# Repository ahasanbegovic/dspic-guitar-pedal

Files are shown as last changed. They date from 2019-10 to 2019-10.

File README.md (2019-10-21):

# dspic-guitar-pedal
A dsPIC-based guitar pedal. It is built around a 16-bit DSP microprocessor. The project is designed to showcase some common practices in digital signal processing, PCB design and embedded programming. The A/D and D/A conversions are done using 12-bits, so the lowpass filters are designed to take away a lot of the higher frequencies, which results in a quite unique and dark sound of the pedal when it is on.

## Circuit

The circuit is designed using `Altium Designer v17.1.5 Build 472`. It is based around a [breakout board](https://download.mikroe.com/documents/full-featured-boards/easy/dspicpro-v4/dspicpro4-mcu-cards-manual-v100.pdf) designed and sold by Mikroelektronika for the [dsPIC60F6014A-PF microcontroller](http://ww1.microchip.com/downloads/en/devicedoc/70143e.pdf). The circuit supports reprogramming of the microcontroller using the [Mikroelektronika dsPIC Flash Programmer](http://www.rlx.sk/mikroelektronika/dspicflash_manual_v102.pdf). The dsPIC has an in-built 12-bit A/D converter, so the only external module (apart from the LM324 OP-AMP) is an [MCP4921 12-bit D/A converter](http://ww1.microchip.com/downloads/en/devicedoc/21897b.pdf). Third party models sourced from [SnapEDA](https://www.snapeda.com/home/). All the project files (including the third party models) can be found in the `circuit` directory. The schematic of the circuit is given below.

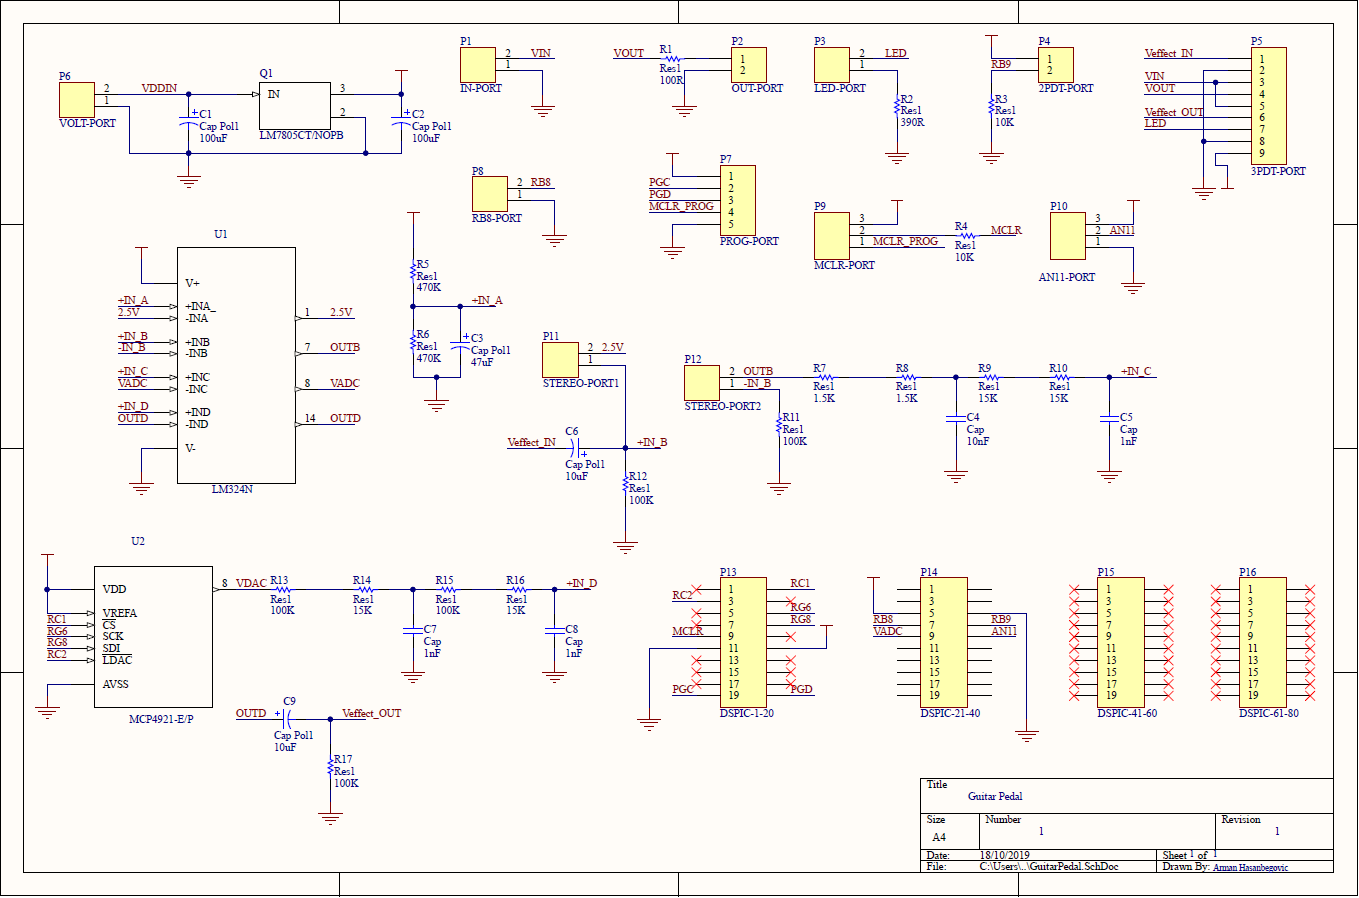
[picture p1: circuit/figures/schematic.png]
Schematic


The PCB is designed on a two-layer Eurocard. Industry-standard output files detailing the design of the PCB can be found in `circuit/Project Outputs for GuitarPedal`.

## Code

The code is written using Mikroelektronika `mikroC PRO for dsPIC v7.1.0`. The essential code (`template.c`) is written in C and given in the `code` directory, and shows how to initiate all the modules of the microcontroller needed, and how to interface the D/A Converter. An example of using that code to create a delay effect is given in `delay.c`.

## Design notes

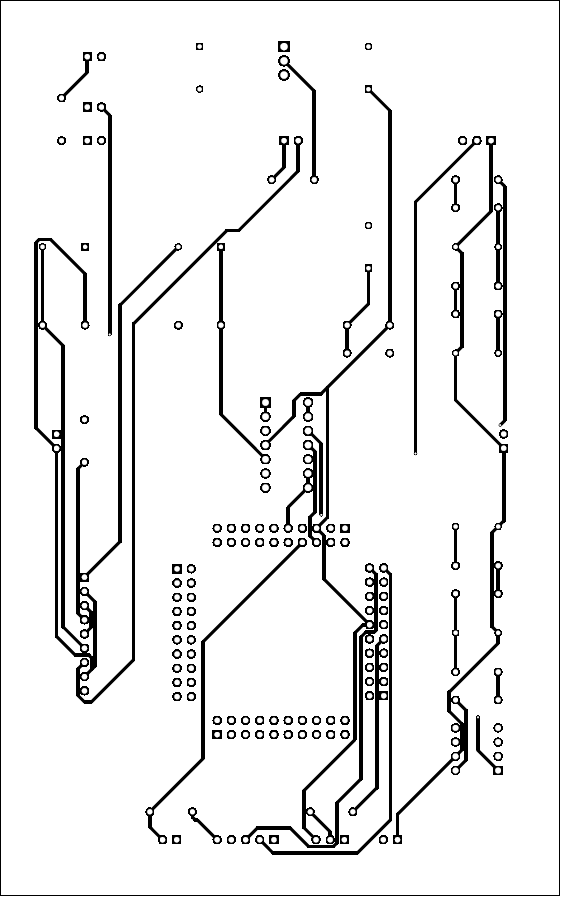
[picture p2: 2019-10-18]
circuit/figures/top_layer.png

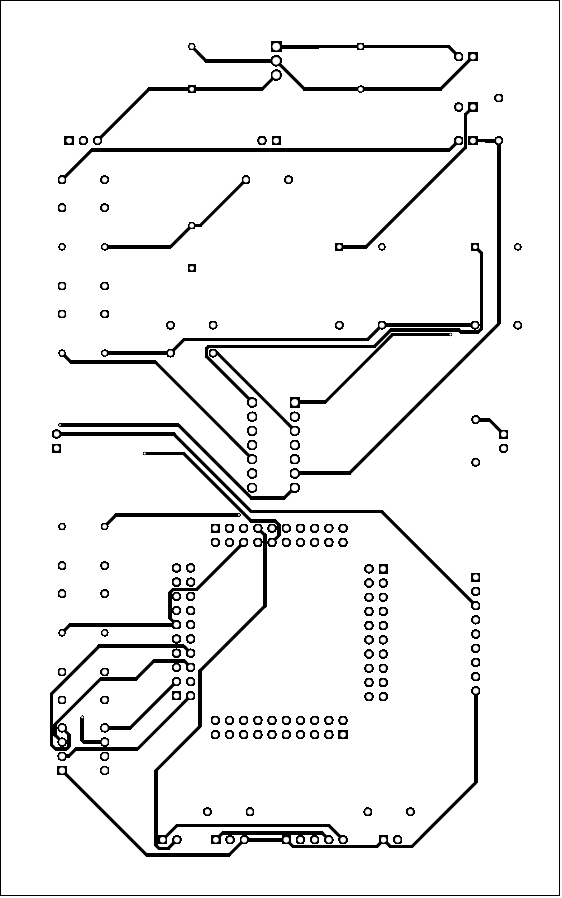
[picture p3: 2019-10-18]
circuit/figures/bottom_layer.png

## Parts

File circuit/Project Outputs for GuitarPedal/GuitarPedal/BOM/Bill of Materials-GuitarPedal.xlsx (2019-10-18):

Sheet: BOM Report
Bill of Materials |  |  | Guitar Pedal
Source Data From: |  | GuitarPedal.PrjPcb
Project: |  | GuitarPedal.PrjPcb
Variant: |  | None
Creation Date: | 18/10/2019 | 13:23:14
Print Date: | 2019-10-18 | 13:26:22
Footprint | Comment | LibRef | Designator | Description | Quantity
RAD-0.3 | Cap | Cap | C4, C5, C7, C8 | Capacitor | 4
RB7.6-15 | Cap Pol1 | Cap Pol1 | C1, C2, C3, C6, C9 | Polarized Capacitor (Radial) | 5
HDR1X2 | IN-PORT, OUT-PORT, LED-PORT, 2PDT-PORT, VOLT-PORT, RB8-PORT, STEREO-PORT1, STEREO-PORT2 | Header 2 | P1, P2, P3, P4, P6, P8, P11, P12 | Header, 2-Pin | 8
HDR1X3 | MCLR-PORT, AN11-PORT | Header 3 | P9, P10 | Header, 3-Pin | 2
HDR1X5 | PROG-PORT | Header 5 | P7 | Header, 5-Pin | 1
HDR1X9 | 3PDT-PORT | Header 9 | P5 | Header, 9-Pin | 1
HDR2X10 | DSPIC-1-20, DSPIC-21-40, DSPIC-41-60, DSPIC-61-80 | Header 10X2 | P13, P14, P15, P16 | Header, 10-Pin, Dual row | 4
*DIP254P762X508-14 | LM324N | LM324N | U1 | Ic Opamp Gp 1.2mhz 14dip | 1
*TO254P1054X470X2600-3 | LM7805CT/NOPB | LM7805CT/NOPB | Q1 | IC REG LINEAR 5V 1A TO220AB | 1
*DIP254P762X432-8 | MCP4921-E/P | MCP4921-E/P | U2 | MCP4921 Series 1 Ch 12-Bit Voltage Output Digital-to-Analog Converter-PDIP-8 | 1
AXIAL-0.3 | Res1 | Res1 | R1, R2, R3, R4, R5, R6, R7, R8, R9, R10, R11, R12, R13, R14, R15, R16, R17 | Resistor | 17
 |  |  |  |  | 45
Approved |  | Notes

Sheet: Project Information
Project Full Path | C:\Users\arman\Documents\ETF\PMBS\Altium\GuitarPedal\GuitarPedal.PrjPcb
Project Filename | GuitarPedal.PrjPcb
Variant Name | None
Data-Source Filename | GuitarPedal.PrjPcb
Data-Source Full Path | C:\Users\arman\Documents\ETF\PMBS\Altium\GuitarPedal\GuitarPedal.PrjPcb
Title | Guitar Pedal
Total Quantity | 45
Report Time | 13:23:14
Report Date | 18/10/2019
Report Date & Tine | 18/10/2019 13:23:14
Output Name | Bill of Materials
Output Type | BOM_PartType
Output Generator Name | BOM
Output Generator Description | Bill of Materials

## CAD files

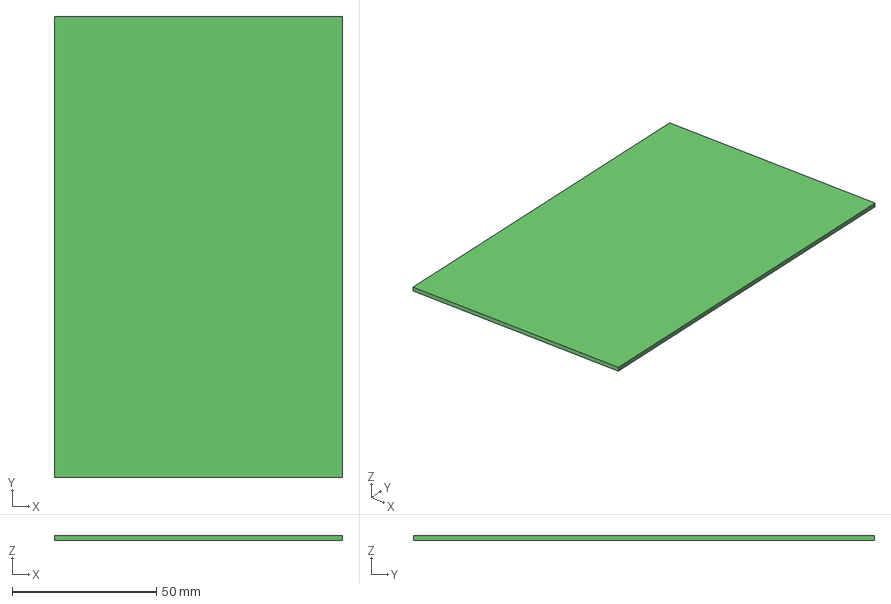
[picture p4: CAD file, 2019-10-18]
circuit/Project Outputs for GuitarPedal/GuitarPedal/ExportSTEP/GuitarPedal.step
100.0 x 160.0 x 1.69 mm

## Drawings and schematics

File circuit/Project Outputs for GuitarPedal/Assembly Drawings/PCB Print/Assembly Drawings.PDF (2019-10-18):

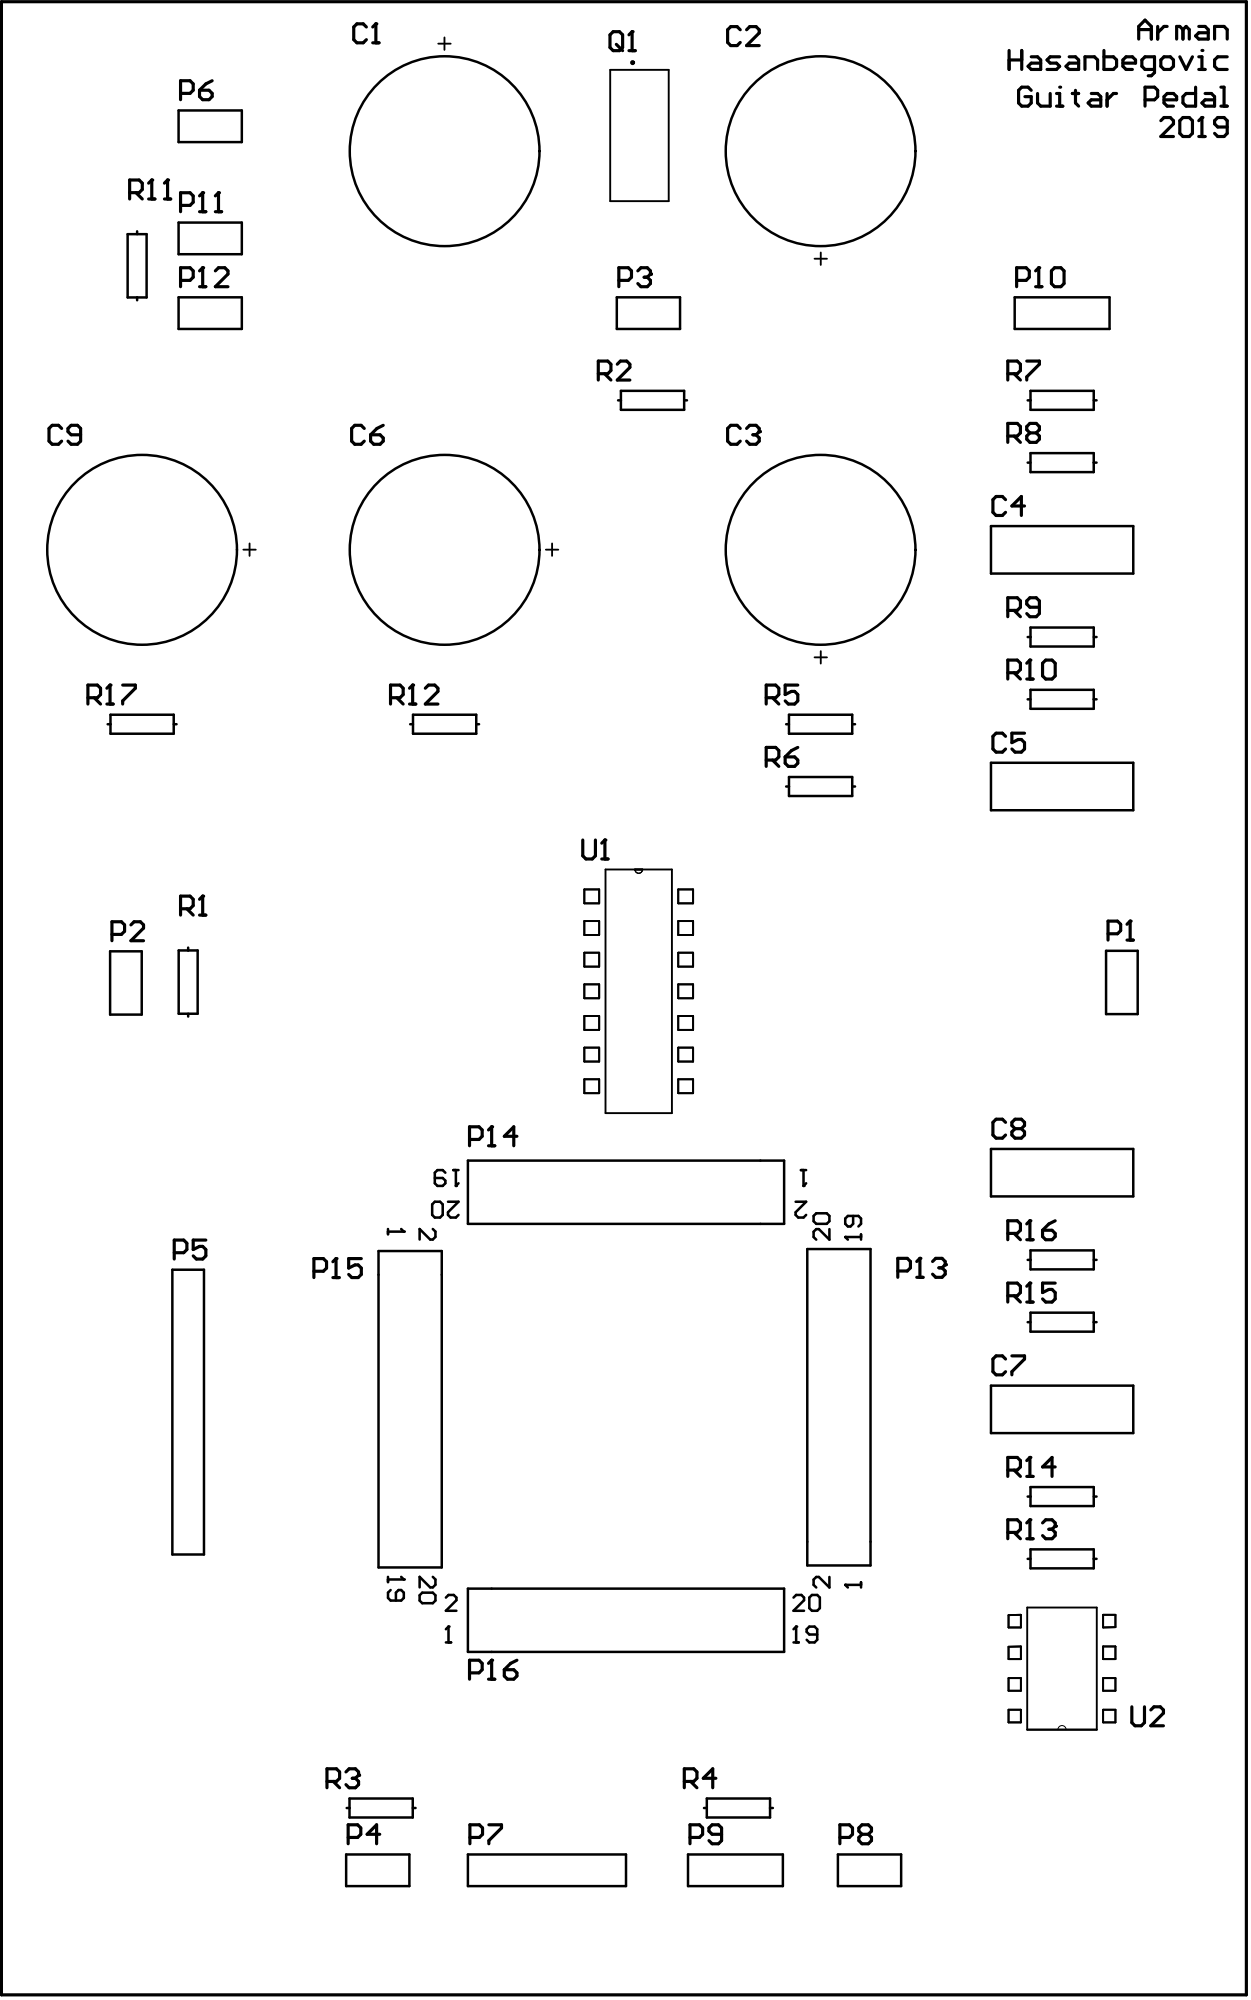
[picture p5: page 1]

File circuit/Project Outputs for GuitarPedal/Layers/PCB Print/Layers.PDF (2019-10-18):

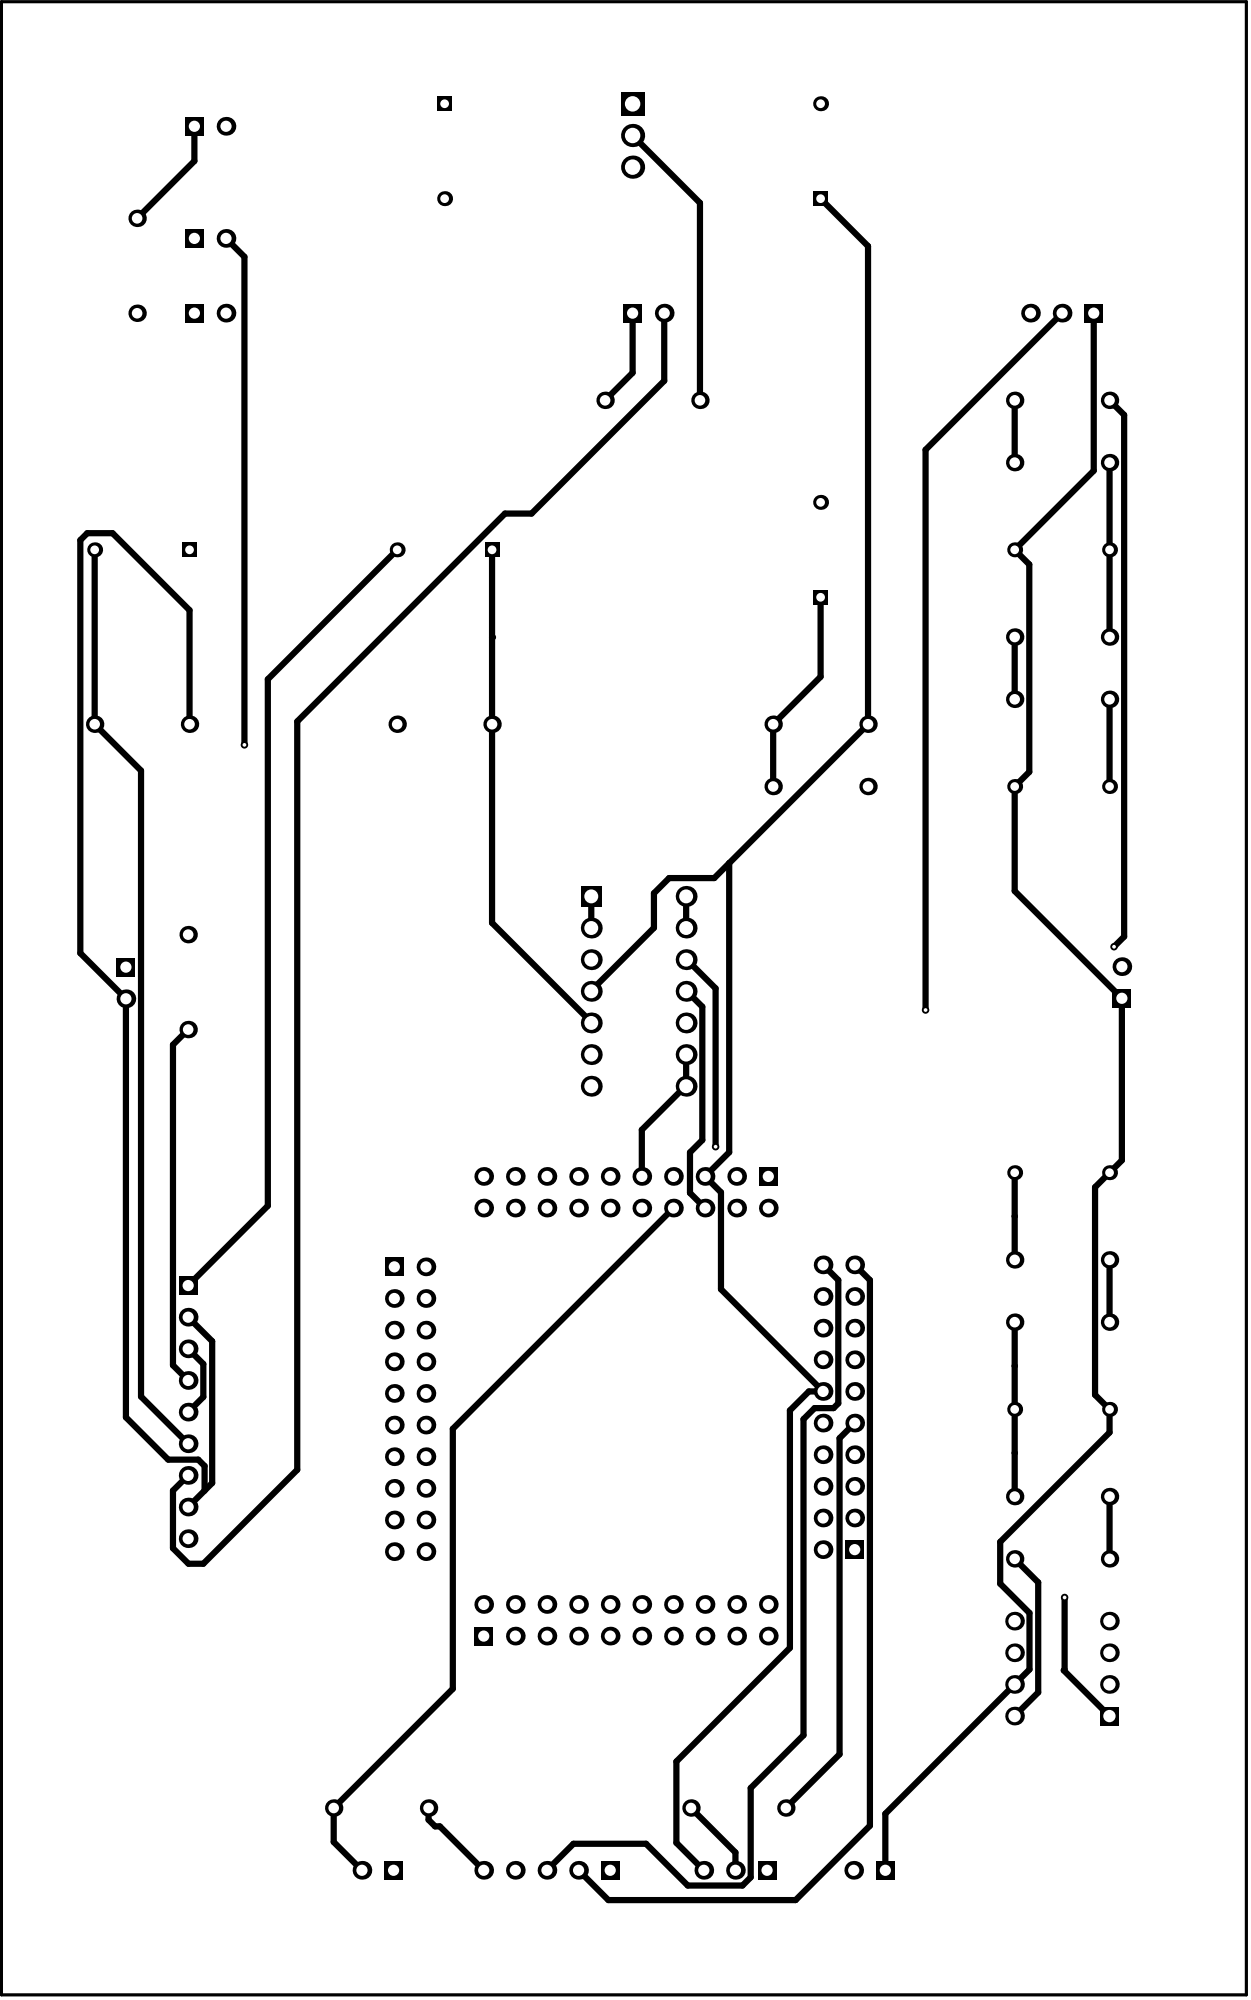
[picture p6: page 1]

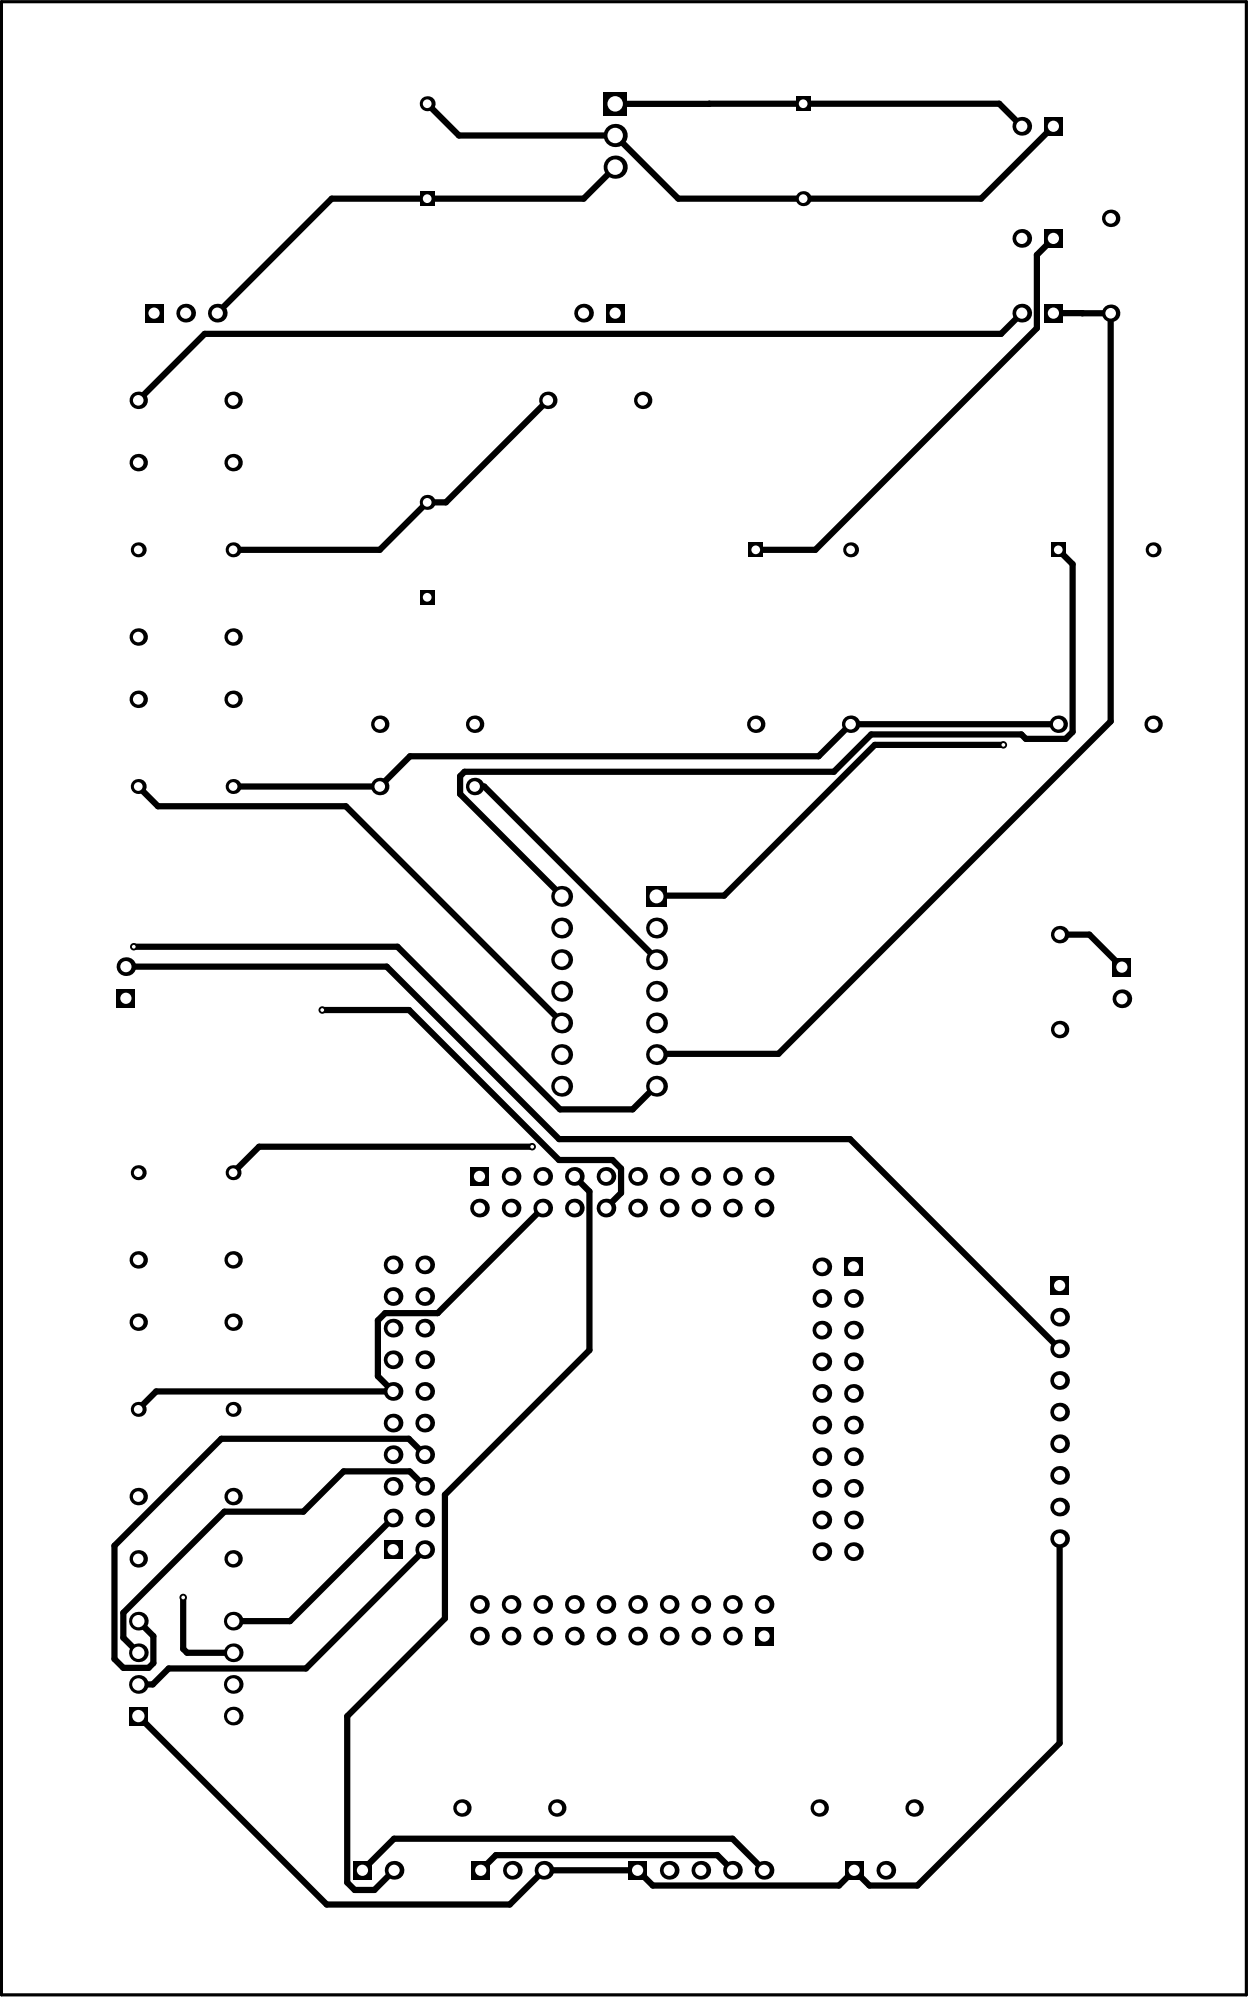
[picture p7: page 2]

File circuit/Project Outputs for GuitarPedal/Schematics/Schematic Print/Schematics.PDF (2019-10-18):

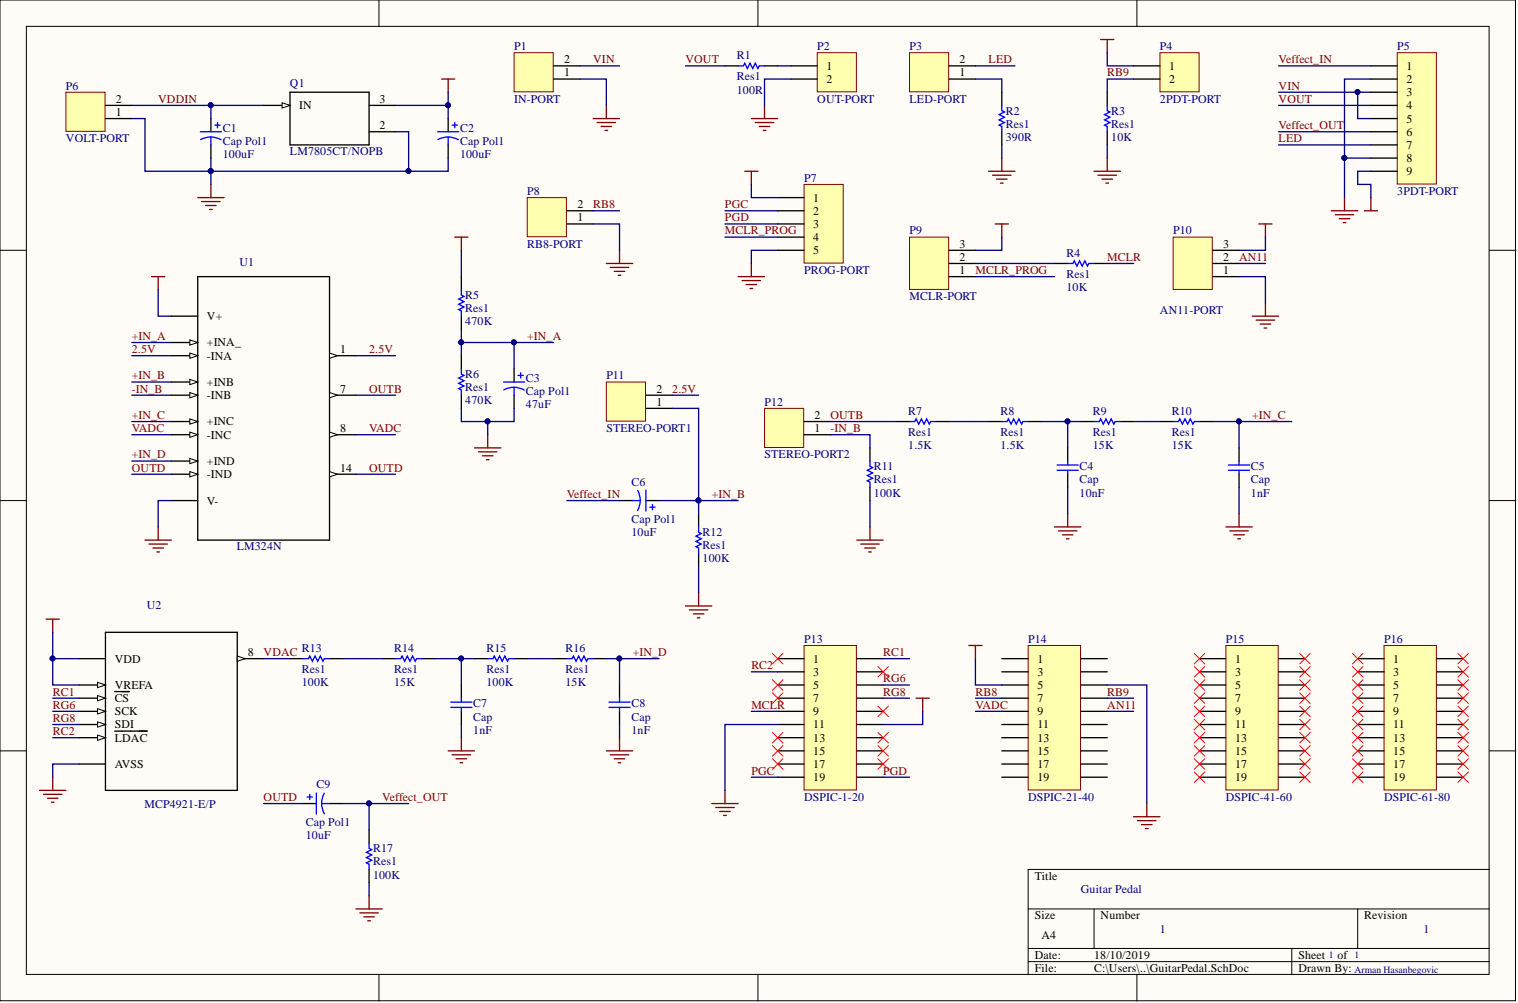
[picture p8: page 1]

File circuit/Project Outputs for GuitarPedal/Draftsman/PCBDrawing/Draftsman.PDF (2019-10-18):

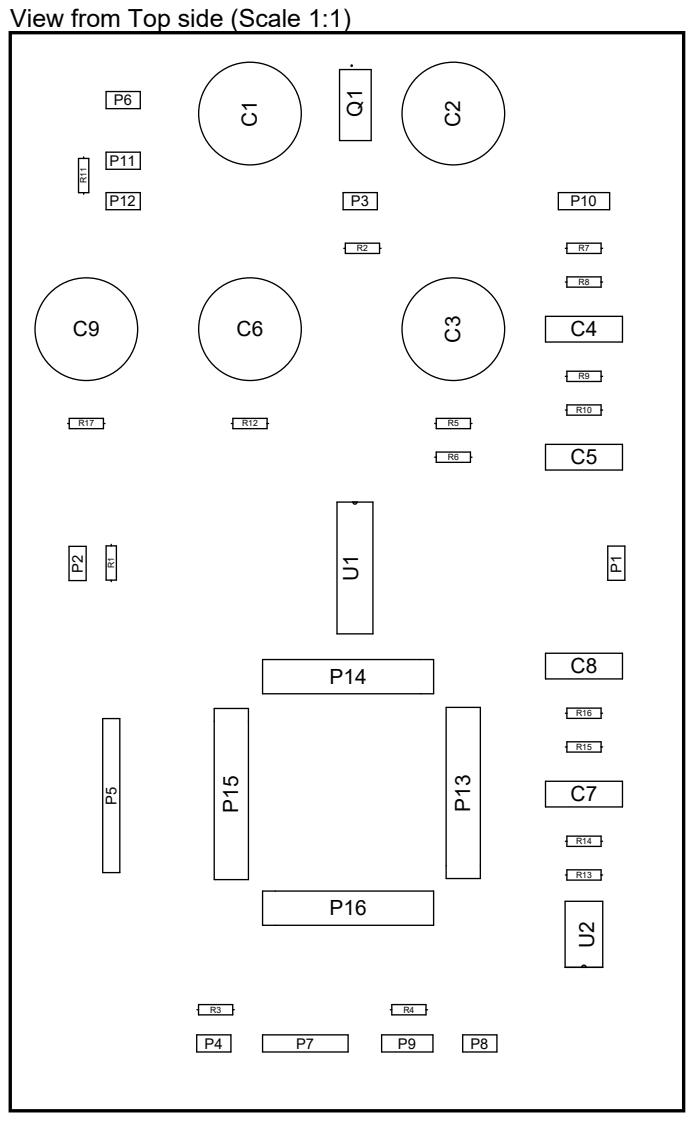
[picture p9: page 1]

View from Top side (Scale 1:1)

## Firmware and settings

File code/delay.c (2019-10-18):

const char CS_PIN = 1;
const char LD_PIN = 2;
const char AN10_PIN = 10;
const char RBx_PIN = 8;
const char IF_PIN = 0;

#define max_buffer_size 4000

unsigned int delay_buffer[max_buffer_size];
unsigned int buffer_size = max_buffer_size;
unsigned int iterator = 0;

void ADC_Init_manual(){
     ADPCFG = 0;
     ADCON1 = 0x0004;
     ADCHS = 0x000A;
     ADCSSL = 0; //No scan
     ADCON3 = 0x0F00; //TAD = internalTCY
     ADCON3 = 0x1003; //ADCS=5 (min TAD for 10MHz is 3*TCY=300ns)
     ADCON2 = 0;
     ADCON1.F15 = 1;
     ADCON1.F9 = 1;
     ADCON1.F8 = 0; // Unsigned fractional
}

int ADC_Read_manual(unsigned int channel){
     ADCHS = channel;
     ADCON1.F1 = 0; //Clear SAMP bit (trigger conversion)
     while(ADCON1.F1 == 0) {
         asm nop; //Wait for DONE bit in ADCON1
     }
     return ADCBUF0;
}

void InitMain() {
    int i;
    for(i = 0; i < max_buffer_size; i++){
       delay_buffer[i] = 2048;
    }
    ADPCFG = 0xFBFF; //10th channel is sampled and coverted
    TRISB.AN10_PIN = 1;  // Set AN0 as input
    TRISB.RBx_PIN = 0;  // Set RBx as output
    LATB.RBx_PIN = 0;
    //ADC1_Init();
    ADC_Init_Manual();

    // Spi2_Init(); // Initialize SPI2 module
    SPI2_Init_Advanced(_SPI_MASTER, // SPI in Master mode
                         _SPI_8_BIT, // 8-bit data
                         _SPI_PRESCALE_SEC_1, _SPI_PRESCALE_PRI_1, //prescaler = 1
                         _SPI_SS_DISABLE,
                         _SPI_DATA_SAMPLE_MIDDLE,
                         _SPI_CLK_IDLE_LOW,
                         _SPI_ACTIVE_2_IDLE //Falling edge
                        );

    TRISC.CS_PIN = 0; // Set CS pin as output
    TRISC.LD_PIN = 0; // Set LD pin as output


    T1IE_bit = 1;         //timer1
    IPC0 = IPC0 | 0x1000; //highest priority
    T1IF_bit = 0;         //first interrupt
    T1CON = 0x8000;       // Internal clock (20 Mhz), prescaler 1:1
    PR1= 226; // Period of Timer1 226 (interrupt every 22.6us, 44.1kHz sampling)
}//~


void DAC_Output(unsigned int valueDAC) {
    unsigned char temp;

    LATC.CS_PIN = 0; // Select DAC module
    LATC.LD_PIN = 0; // Enable data transfer



    // Send 2 bytes of valueDAC variable
    temp = (valueDAC >> 8) & 0x0F; // Prepare hi-byte for transfer
    // It's a 12-bit number, so only
    // lower nibble of high byte is used
    temp |= 0x30; // Set MCP4921 control bits
    Spi2_Write(temp); // Send data via SPI



    temp = valueDAC; // Prepare lo-byte for transfer
    Spi2_Write(temp); // Send data via SPI

    LATC.LD_PIN = 1; // Disable data transfer
    LATC.CS_PIN = 1; // Deselect DAC module
}//~

void Timer1Int() iv IVT_ADDR_T1INTERRUPT {
    int analog_data;
    int output_data;
    int pot_value;

    LATB.RBx_PIN = ~LATB.RBx_PIN;

    pot_value = (ADC_Read_Manual(0x000B) >> 1) & 0xFFF0;
    if (pot_value > 16384){
       pot_value = 16384;
    }


    analog_data = ADC_Read_Manual(0x000A);
    W4 = analog_data;
    W5 = delay_buffer[iterator];
    W6 = 32767 - pot_value; 
    W7 = pot_value;
    CORCON.IF_PIN = 0;
    asm{
        clr A
        mac W4*W6, A, W4, W4, W6, W6
        sac A, #0, W1
        clr B
        mac W5*W7, B, W5, W5, W7, W7
        sac B, #0, W2
    }
    output_data = W1 + W2;
    CORCON.IF_PIN = 1;
    delay_buffer[iterator++] = output_data;


    if (iterator >= buffer_size) iterator = 0;

    DAC_Output(((output_data) >> 4) & 0x0FFF); 

    T1IF_bit = 0;
}

void main() {
 InitMain();
 while (1);
}//~!

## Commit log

2019-10-16 add initial circuit design file
    [GuitarPedal.PcbDoc, GuitarPedal.PrjPcb, GuitarPedal.SchDoc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]
2019-10-16 populate schematic
    [GuitarPedal.SchDoc]
2019-10-17 add pcb layout and output files
    [GuitarPedal.PcbDoc, GuitarPedal.PrjPcb, GuitarPedal.SchDoc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]
2019-10-18 complete output files
    [Bill of Materials-GuitarPedal.xlsx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]
